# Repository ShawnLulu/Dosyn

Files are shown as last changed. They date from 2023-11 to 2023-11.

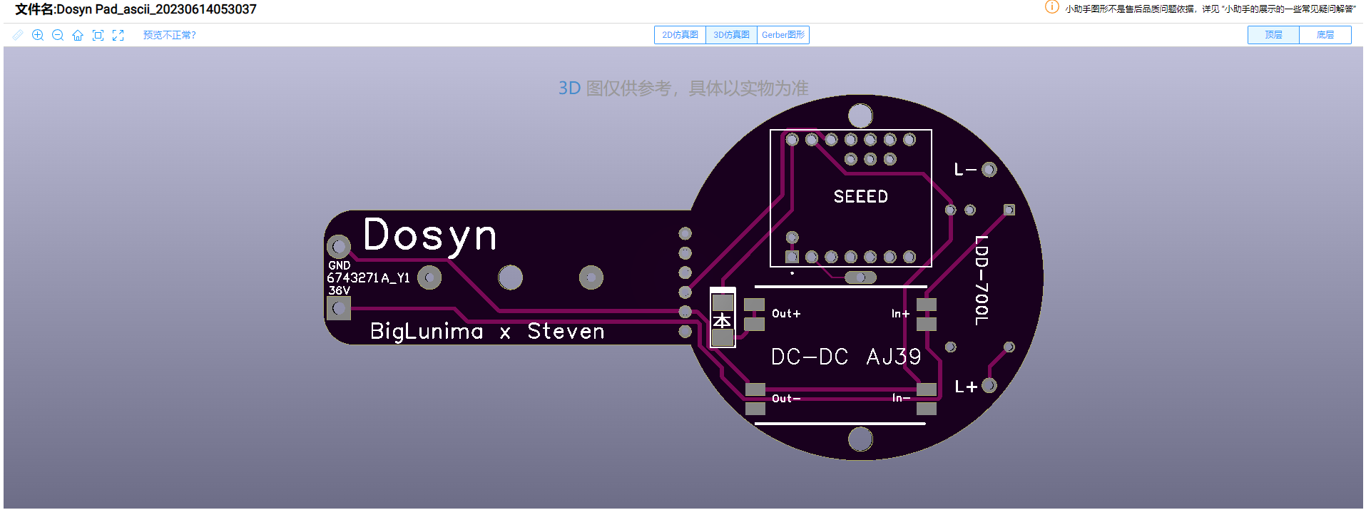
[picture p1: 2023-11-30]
PCB/嘉立创压缩包/PCB.png

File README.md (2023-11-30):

# Dosyn台灯
仿制stevenbennett仿制Dyson Lightcycle仿制出的DIYson(https://github.com/stevenbennett/DIYson)  
声明：结构几乎是照搬Steven的，本人也是看了Steven在YouTube上的合集后，才有复刻的想法。Steven的设计巧妙且细节打磨很到位，起到了巨大的帮助，在此感谢！  
整体是六月份完成的，半年使用下来没什么毛病。  
模型、电路和代码各自的文件夹里都有比较详细的readme，在此不多赘述。并且都可能随版本更新变化，请注意。

## 画个饼先⬇
1、会做一个ESP32C3版本的，并且在横轴正面添加一块长条形墨水屏。预期是利用ESP32C3的WiFi给墨水屏定时刷上天气和备忘录之类的。   
2、可能会更换一颗可以调节色温的灯珠，刚好把APDS-9960传感器的功能榨干，完善一下自动调光。  
3、不太可能会升级一下导电轨道。:blush:

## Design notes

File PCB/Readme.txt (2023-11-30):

--------------------------------------
--------------------------------------
PCB下单前请检查确认尺寸及其细节！！！
PCB下单前请检查确认尺寸及其细节！！！
PCB下单前请检查确认尺寸及其细节！！！
--------------------------------------
--------------------------------------
LED的PCB，有Altium Designer的工程文件，
可以根据需求更改,例如：
1、移除或者替换APDS-9960传感器的过孔。
2、为更合适的DC-DC降压模块更换AJ-39封装。 

LED电路板尺寸在嘉立创月度白嫖尺寸规定内，
但在AD文件转嘉立创EDA的过程中可能需要重新
配置网络、重新覆铜......
（可能还有更多，请注意！）
--------------------------------------
导电轨道的PCB比较简单，只有立创eda的文件。
且在顶部、底部丝印层留有给大伙自定义皮肤
的空间。

其尺寸超出白嫖范围，大约需要30 CNY。
--------------------------------------
实际使用下来，导电轨道有点不太稳定，
不如电线塞在铝型槽里。

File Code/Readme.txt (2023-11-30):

-------------------------------------
版本说明：
Dosyn_0.5是只含+、-、on/off的基础版。
Dosyn_1.0是加入APDS-9960传感器的升级版
增加靠近感应开关、自动调光（没完全弄好）
-------------------------------------
废话：
APDS-9960的功能还没榨干，预期是多做几个
功能的。但是由于结构设计问题，APDS和PCB
的连接线经常断开，烦┗( T﹏T )┛

另外SAMD21应该不会再做了，过段时间应该
会用ESP-IDF做个ESP32-C3版的。

但我真的很懒。

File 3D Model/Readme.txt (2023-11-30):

------------------------------------------
本人使用Autodesk Inventor建模，所以仅提供
.iam .ipt及部分step（因为不是一次弄完，的
有些可能没有转换），如果需要更改零件但找不
到相应step文件，请联系我，会尽快更新。
------------------------------------------

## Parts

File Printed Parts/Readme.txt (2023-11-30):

-------------------------------------
[stl文件前的数字代表需要打印的个数]

打印前请仔细检查零件数量及其细节！！！
打印前请仔细检查零件数量及其细节！！！
打印前请仔细检查零件数量及其细节！！！
-------------------------------------
如果委托商家打印，可以打包小零件到一个stl文件里。
例如Components pack（3D打印商家几乎都有起步价）

需要改进或者需要更多零件请前往3D model文件夹。

建议使用黑色树脂打印，光滑度、形变温度、强度都OK。
+、-、power按钮记得用导电材料打印，没有空着也无所谓。

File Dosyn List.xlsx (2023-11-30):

名称 | 数量 | 类别 | 备注 | 链接 | 单价 | 总价
GT2同步带 | 1 | 结构 | 带宽5mm | https://item.taobao.com/item.htm?spm=a1z0d.6639537/tb.1997196601.21.480874844P1UXw&id=40741171985 | 1.8 | 1.8
透明包胶滑轮 | 6 | 结构 | 内孔径5mm | https://item.taobao.com/item.htm?spm=a1z09.2.0.0.61952e8dVH444n&id=525708632172&_u=j29jqmmlcd35 | 2.76 | 16.56
GT2惰轮 | 1 | 结构 | 16齿 内孔径3mm 带宽6mm | https://item.taobao.com/item.htm?spm=a1z09.2.0.0.758c2e8dvdQFDs&id=529353146204&_u=g2jt2iideb5c | 1 | 1
铝隔离柱 | 1 [10] | 结构 | 10mm*5mm*38mm | https://item.taobao.com/item.htm?spm=a1z0d.6639537/tb.1997196601.104.180174845BlWN3&id=602016481604 | 3.4 | 3.4
铝隔离柱 | 4 [10] | 结构 | 10mm*5mm*6mm | https://item.taobao.com/item.htm?spm=a1z0d.6639537/tb.1997196601.104.180174845BlWN3&id=602016481604 | 2.2 | 2.2
偏心螺母柱 | 2 | 结构 | V槽 高度6mm外径10mm | https://item.taobao.com/item.htm?spm=a1z0d.6639537/tb.1997196601.996.18017484tOw4oI&id=573111863892 | 0.38 | 0.76
轴承底座 | 1 | 结构 | BGSAB6800ZZ | https://item.taobao.com/item.htm?spm=a1z09.2.0.0.557d2e8dirLPW7&id=708356370454&_u=g2jt2iid9321 | 20 | 20
铅珠 配重 1kg | 1 | 结构 | Φ2mm | https://item.taobao.com/item.htm?spm=a1z09.2.0.0.758c2e8dvdQFDs&id=521678597631&_u=g2jt2iidf0df | 26.1 | 26.1
铝型轨道（500mm） | 2 | 结构 | 欧标2020Z (两端攻M5*25mm) | https://item.taobao.com/item.htm?spm=a1z09.2.0.0.758c2e8dvdQFDs&id=702162093110&_u=g2jt2iidacc0 | 12 | 12
欧标铝型 弹珠螺母滑块 | 4 [10] | 结构 | 弹珠螺母20型-M5 | https://item.taobao.com/item.htm?spm=a1z09.2.0.0.557d2e8dirLPW7&id=708930050093&_u=g2jt2iid5962 | 2.8 | 2.8
LED灯珠 | 1 | 灯 | CXA 1512N 4000K 36V 12-18W | https://item.taobao.com/item.htm?spm=a1z09.2.0.0.758c2e8dvdQFDs&id=674402505086&_u=g2jt2iid1dc9 | 10.4 | 10.4
LED透镜、支架、灯杯（三件套） | 1 | 灯 | 50*26mm55deg | https://item.taobao.com/item.htm?spm=a1z09.2.0.0.758c2e8dvdQFDs&id=629233034642&_u=g2jt2iidd1bf | 3 | 3
LED驱动器 | 1 | 电路 | MEAN WELL LDD_700L | https://item.taobao.com/item.htm?spm=a1z0d.6639537/tb.1997196601.24.71bc7484wtONqt&id=717918225591 | 25 | 25
Seeed Xiao SAMD21 | 1 | 电路 | 很早之前买的，大概30？ |  | 30 | 30
36DC/5DC BUCK | 1 | 电路 | 5V/3A AJ39 | https://item.taobao.com/item.htm?spm=a1z09.2.0.0.758c2e8dvdQFDs&id=644686235082&_u=g2jt2iid0242 | 7.2 | 7.2
POGO Pin SMT | 3 | 电路 | Φ2mm*3.5mm | https://item.taobao.com/item.htm?spm=a1z09.2.0.0.758c2e8dvdQFDs&id=718249885086&_u=g2jt2iid2ce4 | 4.2 | 4.2
POGO Pin 单排2PIN DIP | 2 | 电路 | Φ2mm*8mm | https://item.taobao.com/item.htm?spm=a1z09.2.0.0.758c2e8dvdQFDs&id=624202093978&_u=g2jt2iidab5d | 0.9 | 1.8
220AC/36DC电源 | 1 | 电路 | 36V/2A | https://item.taobao.com/item.htm?spm=a1z09.2.0.0.758c2e8dvdQFDs&id=656189866380&_u=g2jt2iid71ec | 18.24 | 18.24
二极管1N5819 SS14 SMA | 1[20] | 电路 | 1N5819贴片SMA丝印SS14 | https://item.taobao.com/item.htm?spm=a1z09.2.0.0.557d2e8dirLPW7&id=542318627622&_u=g2jt2iidab1b | 0.98 | 0.98
RVB2电源线 | 1 | 电路 | RVB2*0.3平方（1米） | https://item.taobao.com/item.htm?spm=a1z09.2.0.0.557d2e8dirLPW7&id=546630740287&_u=g2jt2iid4789 | 0.8 | 0.8
DC电源插头座 | 1 | 电路 | DC插座 5.5*2.1免焊接母头 | https://item.taobao.com/item.htm?spm=a1z09.2.0.0.557d2e8dirLPW7&id=528137679840&_u=g2jt2iid7ddd | 0.38 | 0.38
硅脂 | 1 | 散热 | 买灯珠应该会送的
热管 | 1 | 散热 | 3mm*6mm*300mm | https://item.taobao.com/item.htm?spm=a1z09.2.0.0.758c2e8dvdQFDs&id=14203893936&_u=g2jt2iid77b6 | 19.98 | 19.98
沉头内六角螺丝 M2*4 | n[50] | 紧固件 | M2*4 | https://item.taobao.com/item.htm?spm=a1z09.2.0.0.557d2e8dirLPW7&id=674946028876&_u=g2jt2iid3921 | 2.9 | 2.9
薄平头十字螺丝 M1.6*2.5 | 3[100] | 紧固件 | 黑CM1.6*2 头2.5 | https://item.taobao.com/item.htm?spm=a1z09.2.0.0.557d2e8dirLPW7&id=712109611688&_u=g2jt2iidc466 | 5 | 5
奶酪头一字螺丝 M5*12 | 5[10] | 紧固件 | M5*12 (M5*10可能更合适) | https://item.taobao.com/item.htm?spm=a1z09.2.0.0.557d2e8dirLPW7&id=667877415614&_u=g2jt2iid4e33 | 2.5 | 2.5
薄平头内六角螺丝M5*16 | 4[10] | 紧固件 | 黑M5*16 | https://detail.tmall.com/item.htm?_u=g2jt2iid0320&id=633646359920&spm=a1z09.2.0.0.557d2e8dirLPW7 | 3.49 | 3.49
薄平头内六角螺丝M5*25 | 6[10] | 紧固件 | 黑M5*25 | https://detail.tmall.com/item.htm?_u=g2jt2iid0320&id=633646359920&spm=a1z09.2.0.0.557d2e8dirLPW7 | 4.93 | 4.93
杯头内六角螺丝M5*65 | 1[5] | 紧固件 | M5*65 | https://item.taobao.com/item.htm?spm=a1z09.2.0.0.557d2e8dirLPW7&id=667833607229&_u=g2jt2iidfda0 | 2.72 | 2.72
杯头内六角螺丝M3*20 | 1 | 紧固件
尼龙螺母M3 | 1 | 紧固件
自锁螺母M5 | 6[20] | 紧固件 | M5 (黑锌) | https://detail.tmall.com/item.htm?_u=g2jt2iid481e&id=521351730739&spm=a1z09.2.0.0.557d2e8dirLPW7 | 1.8 | 1.8
金属螺母M5 | 4 | 紧固件
弹簧垫圈M5 | 4 | 紧固件
3D打印 | 1 | 结构 |  |  | 190 | 190
连接LED支架与热管的盖板 | 1 | 结构 | CNC很贵，可以自己用1.5mm铝片做个
PCB-LED | 1 | 电路 | 白嫖 | 嘉立创 | 0 | 0
PCB-RAIL | 1 | 电路 | 太长了白嫖不了ಥ_ಥ | 嘉立创 | 30 | 30
1、名称列连续同色的是一个店里的 |  |  |  |  | CNY: | 451.94
2、数量列格式：用到的数量[整包的数量]

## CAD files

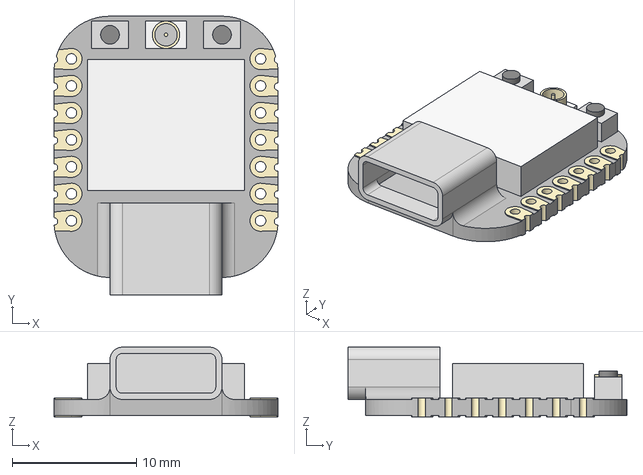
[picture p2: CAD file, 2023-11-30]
3D Model/STEP/Seeed Xiao esp32c3/Seeed Xiao esp32c3.stp
18.0 x 22.4 x 5.60 mm

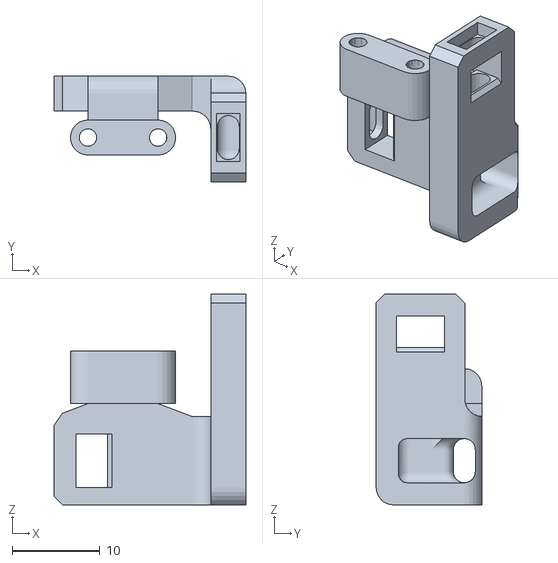
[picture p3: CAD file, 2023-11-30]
3D Model/STL/1 Pogo Pin Clip.stl
21.8 x 12.1 x 24.0

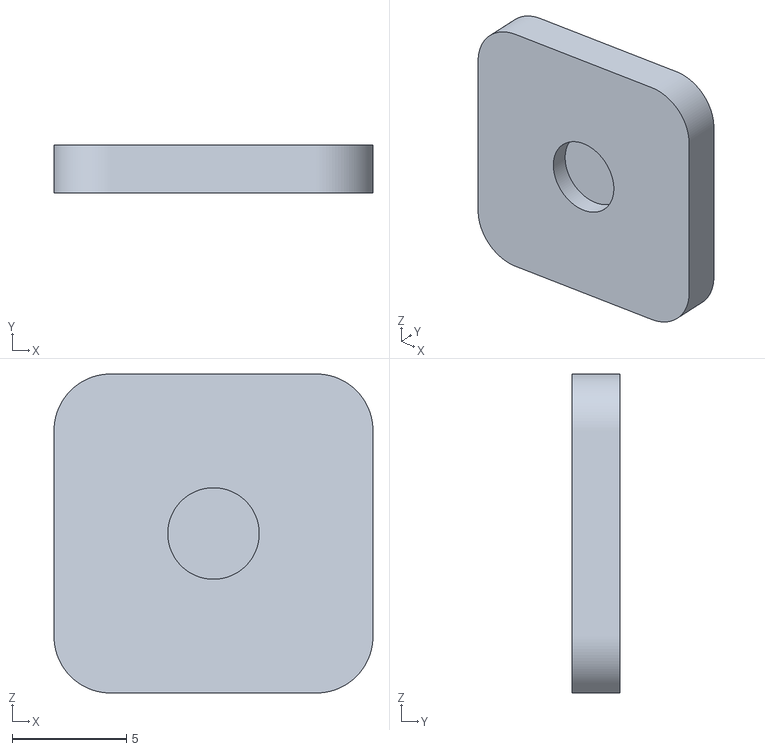
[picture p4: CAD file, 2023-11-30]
3D Model/STL/LED/1 Increase Brightness Button.stl
13.9 x 2.10 x 13.9

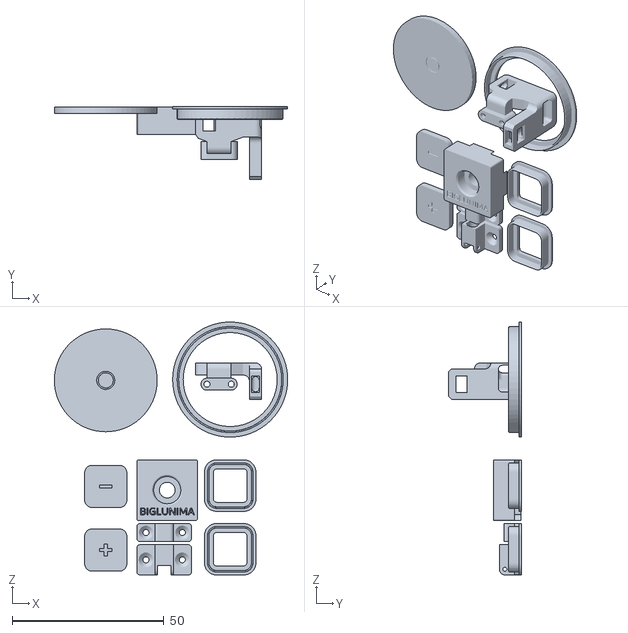
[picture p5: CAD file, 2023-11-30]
Printed Parts/1 Components pack.stl
77.0 x 24.0 x 83.5

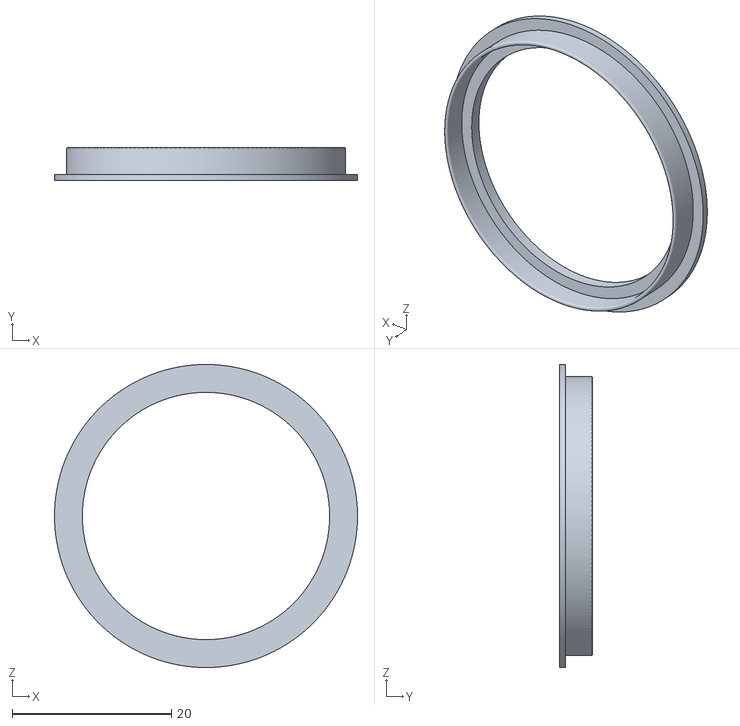
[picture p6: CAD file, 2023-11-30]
3D Model/STL/LED/1 Power Button Socket.stl
38.0 x 4.20 x 38.0

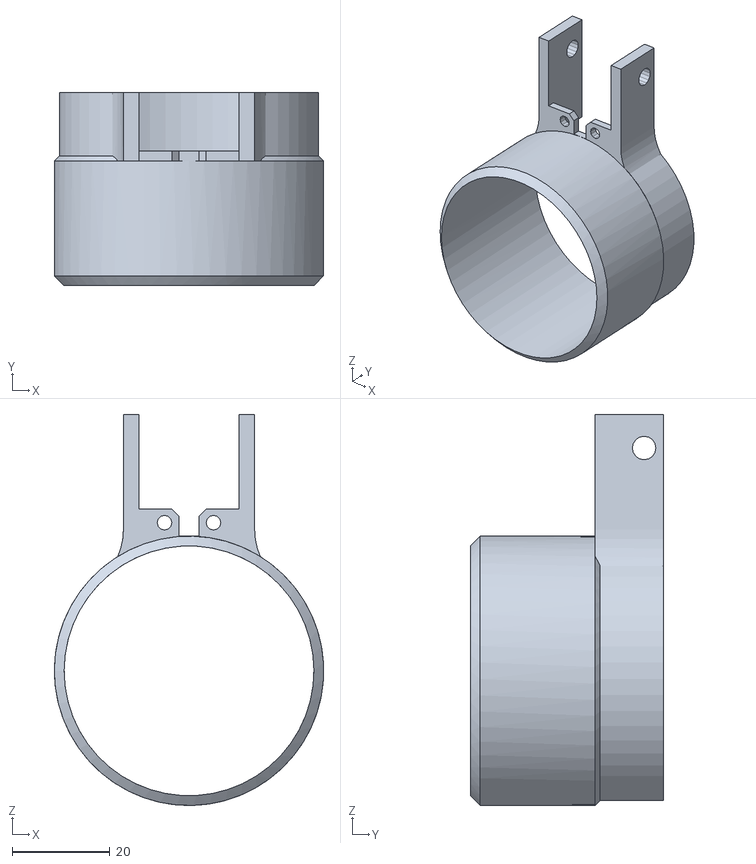
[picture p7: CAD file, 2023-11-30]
Printed Parts/1 LED Cover - Bottom.stl
55.0 x 39.5 x 79.8

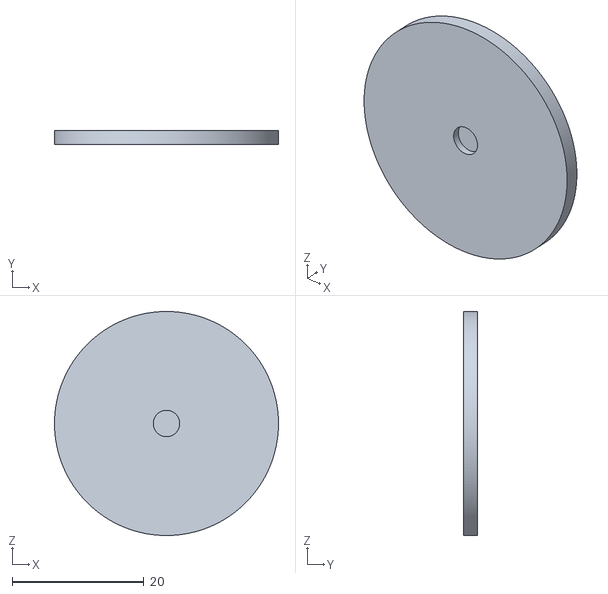
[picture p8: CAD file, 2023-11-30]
3D Model/STL/LED/1 Power Button.stl
33.9 x 2.10 x 33.9

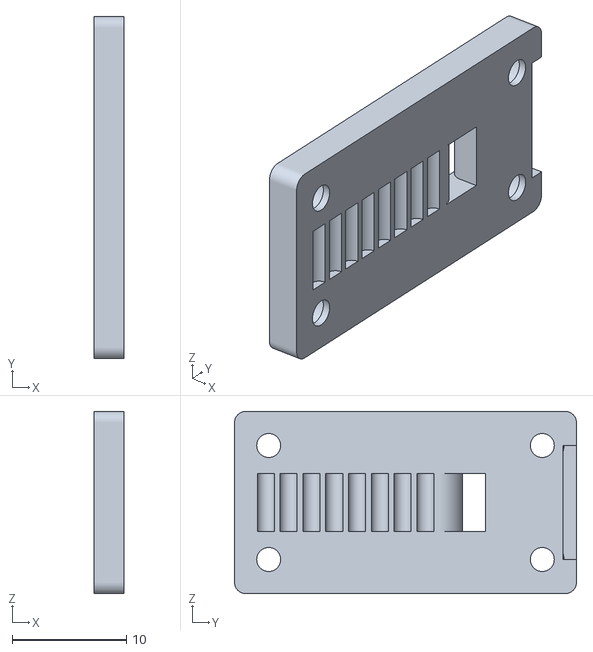
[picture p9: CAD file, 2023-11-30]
Printed Parts/1 Counterweight Belt Clip.stl
2.60 x 30.0 x 16.0

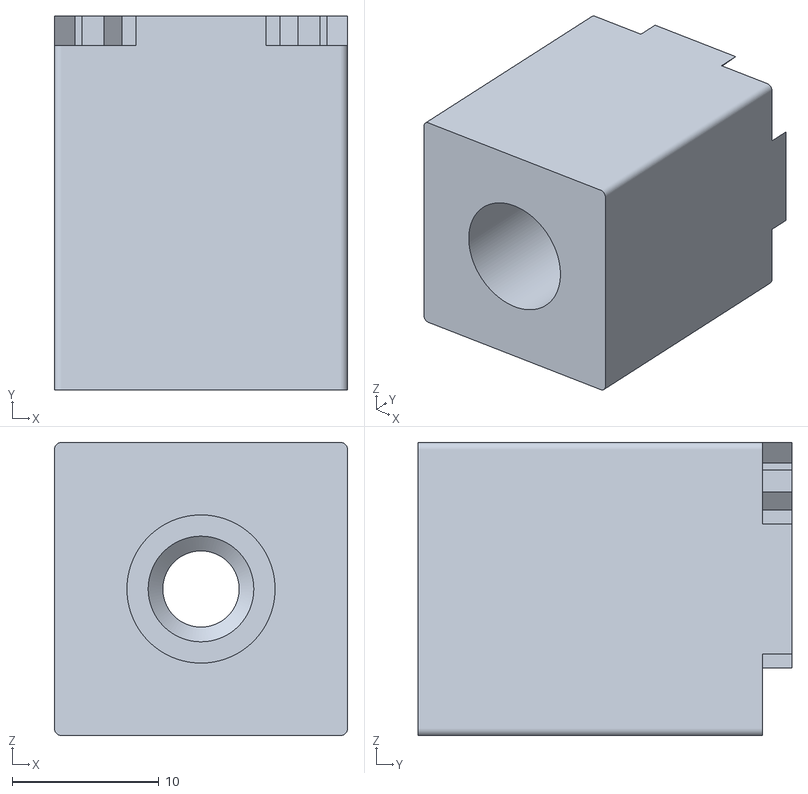
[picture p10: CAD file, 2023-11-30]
Printed Parts/1 Base.stl
20.0 x 25.5 x 20.0

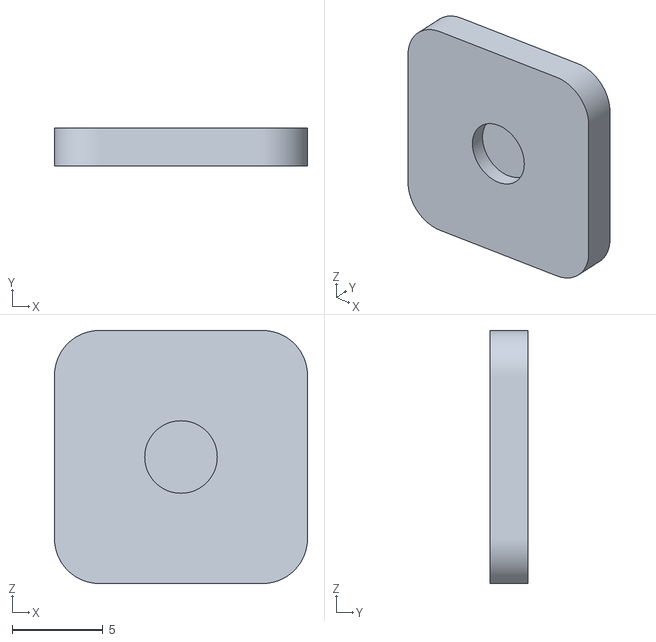
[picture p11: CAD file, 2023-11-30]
3D Model/STL/LED/1 Decrease Brightness Button.stl
13.9 x 2.10 x 14.0

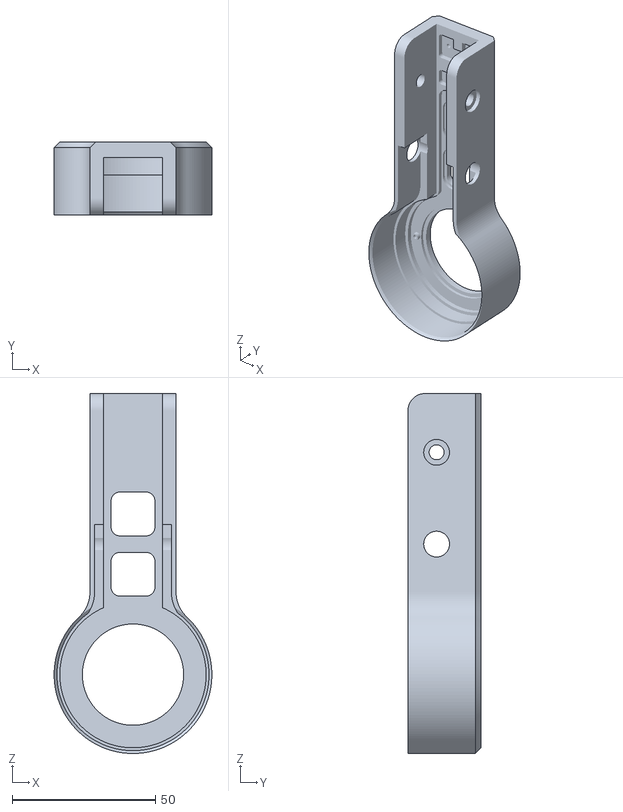
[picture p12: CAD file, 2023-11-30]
Printed Parts/1 LED Cover - Top.stl
55.0 x 25.5 x 125.5

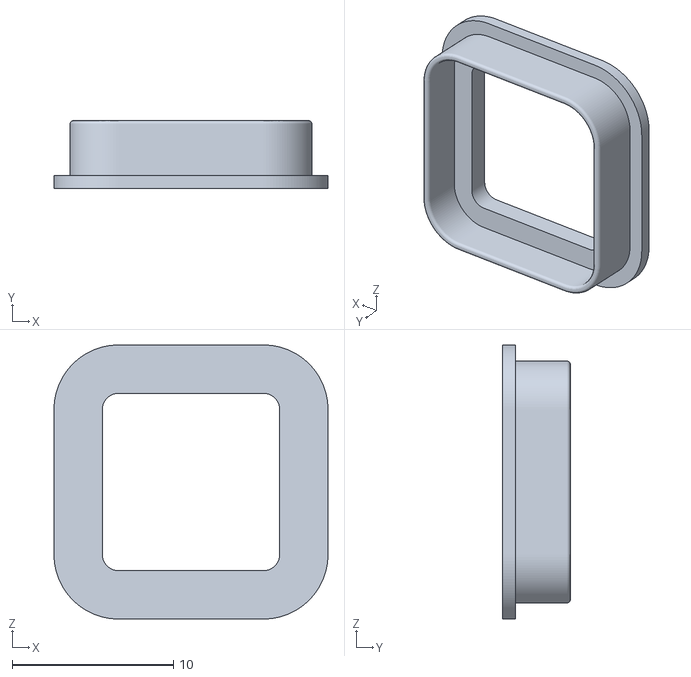
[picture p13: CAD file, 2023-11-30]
3D Model/STL/LED/2 Brightness Button Socket.stl
17.0 x 4.20 x 17.0

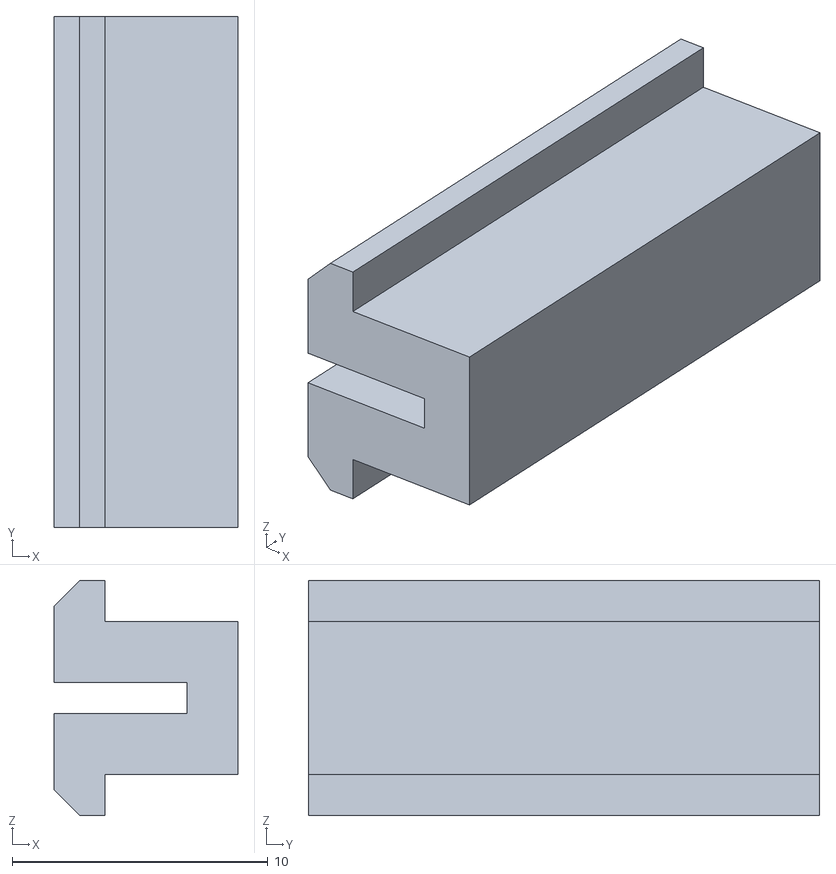
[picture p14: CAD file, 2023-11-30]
Printed Parts/2 Counterweight - Flex Tab.stl
7.20 x 20.0 x 9.20

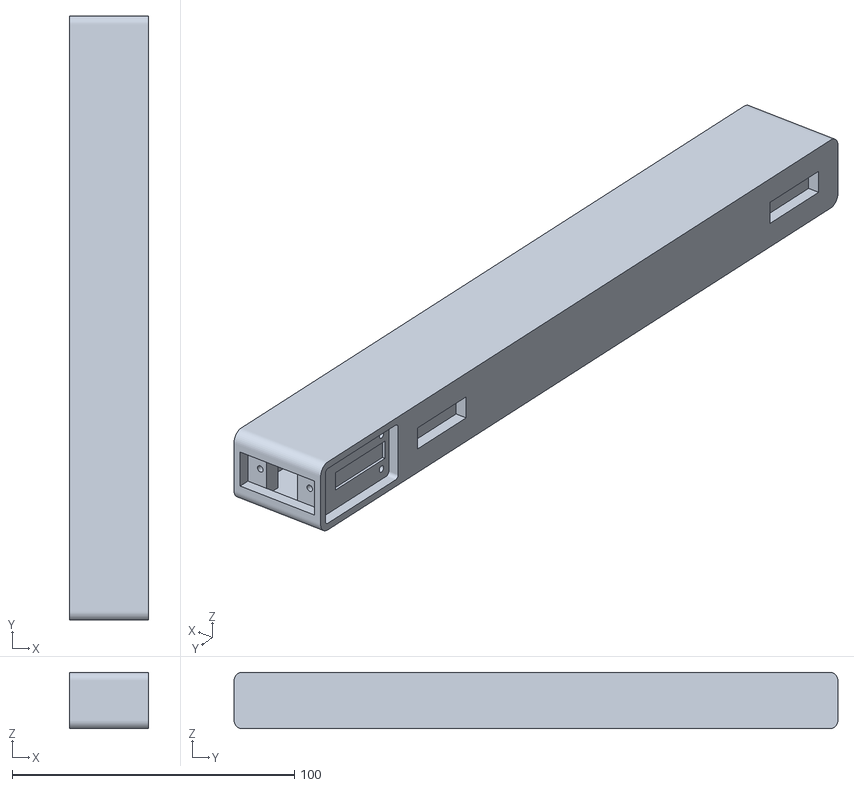
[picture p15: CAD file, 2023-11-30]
Printed Parts/1 Coutnterweight Enclosure.stl
28.0 x 214.0 x 20.0

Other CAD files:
3D Model/STL/LED/1 LED Cover - Bottom.stl
Printed Parts/1 Carriage.stl
Printed Parts/1 Belt Clip.stl
Printed Parts/1 Coutnterweight Lid.stl
3D Model/Carriage/Belt Clip.ipt
3D Model/Carriage/Carriage Streamlined.iam
3D Model/Carriage/Carriage.ipt
3D Model/Carriage/Component2.ipt
3D Model/Carriage/Component3.ipt
3D Model/Carriage/Component8.ipt
3D Model/Carriage/Pogo Pin Clip.ipt
3D Model/Carriage/Pogo Pin.ipt
3D Model/Carriage/Routed Spacer.ipt
3D Model/Carriage/Wheel.iam
3D Model/Carriage/Wheel_1.iam
3D Model/Carriage/Wheel_2.iam
3D Model/Carriage/Wheel_3.iam
3D Model/Carriage/Wheel_4.iam
3D Model/Carriage/Wheel_5.iam
3D Model/Counterweight/Counterweight Belt Clip.ipt
3D Model/Counterweight/Counterweight Enclosure.ipt
3D Model/Counterweight/Counterweight Flex Tab.ipt
3D Model/Counterweight/Counterweight Lid.ipt
3D Model/Dosyn.iam
3D Model/Electronics/Board.iam
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

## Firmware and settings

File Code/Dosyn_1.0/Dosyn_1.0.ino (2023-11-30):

#include "Adafruit_FreeTouch.h"
#include "Adafruit_APDS9960.h"

//create the APDS9960 object
Adafruit_APDS9960 apds;
/////////////////////////////////////////////////////////////////////////////
//引脚分布↓
#define INT_PIN A3
#define LED_PWM_Pin A2
Adafruit_FreeTouch qt_1 = Adafruit_FreeTouch(A1, OVERSAMPLE_4, RESISTOR_50K, FREQ_MODE_NONE);//power 
Adafruit_FreeTouch qt_2 = Adafruit_FreeTouch(A7, OVERSAMPLE_4, RESISTOR_50K, FREQ_M ODE_NONE);//+
Adafruit_FreeTouch qt_3 = Adafruit_FreeTouch(A6, OVERSAMPLE_4, RESISTOR_50K, FREQ_MODE_NONE);//-

int qt_Threshold = 850;//QT灵敏度
int Proximity_Threshold = 100;//接近灵敏度
int counter = 0;
int counter1=0;
int Brightness = 0;//10%亮度为最低 brightness为目标亮度
int step = 10;
int Proximity_num = 0;
bool power = false;
bool fading = false;
bool closing = false;
bool Proximity_Short = false;
bool Proximity_Long  = false;
uint16_t r, g, b, c;


int cycle=0;
float distance,increment;
int GapTime,ADD,target;

void fadeBetween(void);////计算
/////////////////////////////////////////////////////////////////////////////
void fadeBetween(int start,int end,int direction){
  
  Serial.println("fading------------------");
  distance = abs(start - end);
  increment = distance/step;
  Serial.print("distance ");
  Serial.println(distance);
  Serial.print("increment ");
  Serial.println(increment);
  Serial.print("start ");
  Serial.println(start);
  Serial.print("end ");
  Serial.println(end);
  Serial.print("direction ");
  Serial.println(direction);

  cycle = start;
  GapTime  = 30/increment;             //increment越高 打入淡出越快 总时间不变
  Serial.print("cycle ");
  Serial.println(cycle);
  Serial.print("GapTime ");
  Serial.println(GapTime);
  
  ADD    = direction;
  target = end;
  fading = true;
}
/////////////////////////////////////////////////////////////////////////////
void setup() {
  Serial.begin(115200);
  //while (!Serial);
  //Serial.println("Ready");
  pinMode(INT_PIN, INPUT_PULLUP);
  pinMode(LED_PWM_Pin, OUTPUT);
  Brightness = 10;
/////////////////////////////////////////////////////////////////////////////
  if(!apds.begin()){
    Serial.println("failed to initialize device! Please check your wiring.");
  }
  else Serial.println("Device initialized!");
  //enable proximity mode
  apds.enableProximity(true);
  //set the interrupt threshold to fire when proximity reading goes above Proximity_Threshold
  apds.setProximityInterruptThreshold(0,Proximity_Threshold);
  //enable the proximity interrupt
  apds.enableProximityInterrupt();
  //enable color sensign mode
  apds.enableColor(true);

  apds.clearInterrupt();
/////////////////////////////////////////////////////////////////////////////
  if (! qt_1.begin())  
    Serial.println("Failed to begin qt on pin A0");
  if (! qt_2.begin())  
    Serial.println("Failed to begin qt on pin A7");
  if (! qt_3.begin())  
    Serial.println("Failed to begin qt on pin A2");
}


////////////////////////////////////////////////////////////////////////////
void loop() {
////接近感应
  //When the interrupt pin goes low
  if(!digitalRead(INT_PIN)){
    Serial.println(apds.readProximity());
    closing = true;
    Serial.println("closing");
    Serial.println(closing);
    Proximity_num ++;
    Serial.println("Proximity_num");
    Serial.println(Proximity_num);

    if(apds.readProximity()<Proximity_Threshold){
      if(30<Proximity_num&&Proximity_num<270){
        Serial.println("短按");
        Proximity_Short = true;
      }else if(280<Proximity_num&&Proximity_num<670){
        Serial.println("长按");
        Proximity_Long = true;                    
        apds.getColorData(&r, &g, &b, &c);
        Serial.print("red: ");
        Serial.print(r);
        Serial.print(" green: ");
        Serial.print(g);
        Serial.print(" blue: ");
        Serial.print(b);
        Serial.print(" clear: ");
        Serial.println(c);
        Serial.println();
        
        Serial.print(" Temperature: ");
        Serial.print(apds.calculateColorTemperature(r,g,b));
        Serial.print(" Lux: ");
        Serial.println(apds.calculateLux(r,g,b));
        Serial.println();        
      }
      closing = false;
      Serial.println("closing");
      Serial.println(closing);
      Proximity_num = 0;
      Serial.println("Proximity_num");
      Serial.println(Proximity_num);
      apds.clearInterrupt();
    }
  }
////触摸检测----------------------------------------------
  int qt1 = 0;
  int qt2 = 0;
  int qt3 = 0; 
  qt1 = qt_1.measure(); 
  qt2 = qt_2.measure();
  qt3 = qt_3.measure();
////保持cycle亮度
  if(!fading){analogWrite(A2,cycle/10*25);}
////淡入淡出
  if(fading){
    while(cycle != target){
    if((millis()-counter1)>GapTime){
      counter1 = millis();
      cycle = cycle + ADD;
      analogWrite(A2, int(cycle/10*25));
      Serial.print("CN ");
      Serial.println(cycle);
      }
    }
    if((cycle)==(target))
    {
    fading = false;
    Serial.println("faded------------------");
    }
  }
//////////////////////////////////////////////////////
///不在fading 且按键时 可以下一次操作 
  else if((millis()-counter)>300){           
    counter = millis();
////OFFline-------------------------------------------
////开灯 未经reset 仍保持熄灯前Brightness---------------
    if(!power){ 
      if(qt1>qt_Threshold||Proximity_Short){
        power = true;
        Proximity_Short = false;
        fadeBetween(0, Brightness, 1);
        Serial.print("QT 1: POWER "); 
        Serial.println(power);
        Serial.println(apds.readProximity());
        apds.clearInterrupt();
      }
    }else{
////Online--------------------------------------------
////关机键--------------------------------------------
      if(qt1>qt_Threshold||Proximity_Short){
        power = false;
        Proximity_Short = false;
        fadeBetween(Brightness, 0, -1); 
        Serial.println("QT 1: POWER "); 
        Serial.println(power);
        Serial.println(apds.readProximity());
        apds.clearInterrupt();
        delay(300);
      }
////加键----------------------------------------------
      else if((qt2>qt_Threshold)&&Brightness != 100){
        fadeBetween(Brightness, (Brightness + step), 1);
        Brightness = Brightness + step;
        Serial.print("QT 2: INCREASE   Brighiness "); 
        Serial.println(Brightness);
      }
////减键----------------------------------------------
      else if((qt3>qt_Threshold)&&Brightness != step){
        fadeBetween(Brightness, (Brightness - step), -1);
        Brightness = Brightness - step;
        Serial.print("QT 3: DECREASE    Brighiness "); 
        Serial.println(Brightness);
      }
    }
  }
}
